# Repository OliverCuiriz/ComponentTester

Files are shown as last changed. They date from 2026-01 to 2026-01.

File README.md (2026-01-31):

# Component Tester – Proyecto de residencia profesional

Este repositorio contiene mi **proyecto de residencia profesional: Dispositivo para el diagnóstico y medición de componentes electrónicos**, desarrollado en el **Instituto Tecnológico de Tijuana** para el **CETis No. 58**.

El proyecto consiste de un probador de componentes electrónicos capaz de evaluar hasta **20 familias de componentes**, proporcionando información del estado de cada componente. El sistema está diseñado para apoyar el trabajo educativo y práctico en los estudiantes de electrónica en el CETis No. 58, permitiendo a los usuarios verificar el correcto funcionamiento de sus componentes electrónicos utilizados en sus prácticas de laboratorio.

## Familias de componentes soportados

- **Compuertas lógicas:** 74LS00 (NAND), 74LS02 (NOR), 74LS04 (NOT), 74LS08 (AND), 74LS32 (OR) y 74LS86 (XOR)
- **Reguladores de voltaje lineales:** LM317, LM337, LM7805, LM7812 y LM7912  
- **Diodos:** diodos rectificadores (familia 1N400x), LEDs y diodos Schottky 
- **Temporizador y OpAmp:** NE555 y LM741  
- **Motores:** servomotores SG90 / MOT1XX  y motor a pasos unipolar 28BYJ-48 
- **Otros componentes:** resistencias y capacitores

## Estructura del repositorio

Este repositorio está organizado en carpetas individuales que contienen todos los recursos relacionados con el proyecto. Estos incluyen el código fuente del proyecto, el esquema eléctrico, los archivos de diseño 3D de la PCB y la carcasa, y los recursos gráficos utilizados para el menú de la interfaz de usuario.

### Para abrir estos archivos se necesita el siguiente software:
- **Arduino IDE 2.6.3** recomendable
- **KiCad 9**
- **SolidWorks 2022**, o bien, cualquier software que pueda abrir archivos con extensión **.STL**
- **Photopea**, o bien, **Photoshop**

## Advertencias importantes
- Debido a un bug con los botones para navegar en el menú, se tiene que hacer un puente entre el pin 17 y pin 2 del ATmega2560. Esto se ve reflejado en el codigo fuente del proyecto pero no en el diseño de la PCB actual.
- El conector JST XH2.54 macho que se utiliza para el motor a pasos 28BYJ-48 está al revés en el diseño de la PCB.

**Ambos errores se pueden corregir modificando directamente la PCB en KiCad y generar otro diseño.** Si se quisiera fabricar la PCB tal y como está entonces se tienen que hacer esas dos modificaciones.

## Fotografía del proyecto

20251230_010616-Photoroom

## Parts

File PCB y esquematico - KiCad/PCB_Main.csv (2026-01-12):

Reference | Value | Datasheet | Footprint | Qty | DNP
C202,C206,C212,C300,C301,C302,C303,C304,C305,C306,C307,C308,C309,C401,C402,C600,C700 | 100nF | ~ | Capacitor_SMD:C_0805_2012Metric | 17
C500 | 10nF | ~ | Capacitor_SMD:C_0805_2012Metric | 1
R100,R101,R102,R105,R107,R110,R215,R228,R402 | 220 | ~ | Resistor_SMD:R_0805_2012Metric | 9
R103,R108,R111,R204,R205,R210,R211,R217,R218,R223,R224,R230,R231,R403,R503,R504 | 10k | ~ | Resistor_SMD:R_0805_2012Metric | 16
R104,R106,R109,R112,R500,R501 | 120k | ~ | Resistor_SMD:R_0805_2012Metric | 6
R203,R209,R216,R222,R229,R502 | 33k | ~ | Resistor_SMD:R_0805_2012Metric | 6
R300 | 330 | ~ | Resistor_SMD:R_0805_2012Metric | 1
R301 | 680 | ~ | Resistor_SMD:R_0805_2012Metric | 1
R400 | 2.2k | ~ | Resistor_SMD:R_0805_2012Metric | 1
R401 | 2.4k | ~ | Resistor_SMD:R_0805_2012Metric | 1
R900,R901,R902,R903,R904 | 4.7k | ~ | Resistor_SMD:R_0805_2012Metric | 5
R1000,R1001,R1002,R1100,R1101,R1102,R1103,R1104 | 1k | ~ | Resistor_SMD:R_0805_2012Metric | 8

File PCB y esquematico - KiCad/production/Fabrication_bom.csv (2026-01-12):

Designator | Footprint | Quantity | Value | LCSC Part #
_42, _41, _40, _39, _38, _37, _36, _35, _34, _33, _32, _31, _30, _29, _28, _27, _26, _25, _24, _23, _22, _21, _20, _19, _18, _17, _16, _15, _14, _13, _12, _11, _10, _9, _8, _7, _6, _5, _4, _3, _2, |  | 42
C202, C206, C209, C212, C300, C301, C302, C303, C304, C305, C306, C307, C308, C309, C401, C402, C600, C700 | 0805 | 18 | 100nF | C28233
C500 | 0805 | 1 | 10nF | C1710
R100, R101, R102, R105, R107, R110, R215, R228, R402 | 0805 | 9 | 220 | C17557
R1000, R1001, R1002, R1100, R1101, R1102, R1103, R1104 | 0805 | 8 | 1k | C17513
R103, R108, R111, R204, R205, R210, R211, R217, R218, R223, R224, R230, R231, R403, R503, R504 | 0805 | 16 | 10k | C17414
R104, R106, R109, R112, R500, R501 | 0805 | 6 | 150k | C17470
R203, R209, R216, R222, R229, R502 | 0805 | 6 | 33k | C17633
R300 | 0805 | 1 | 330 | C17630
R301 | 0805 | 1 | 680 | C17798
R400 | 0805 | 1 | 2.2k | C17520
R401 | 0805 | 1 | 2.4k | C17526
R900, R901, R902, R903, R904 | 0805 | 5 | 4.7k | C17673

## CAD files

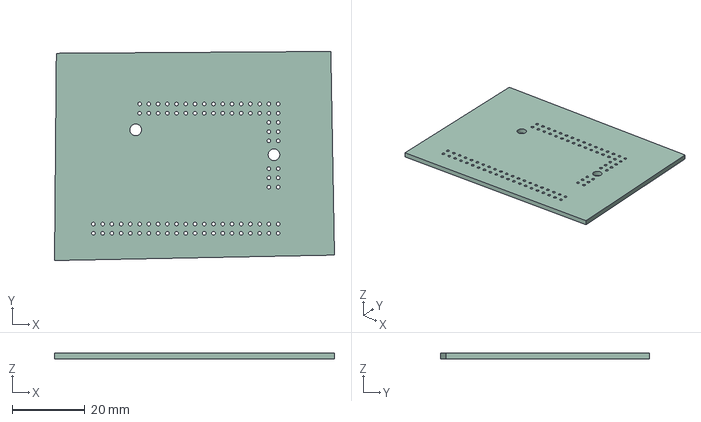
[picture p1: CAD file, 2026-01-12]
PCB y esquematico - KiCad/PCB_Main.step
77.0 x 57.5 x 1.60 mm

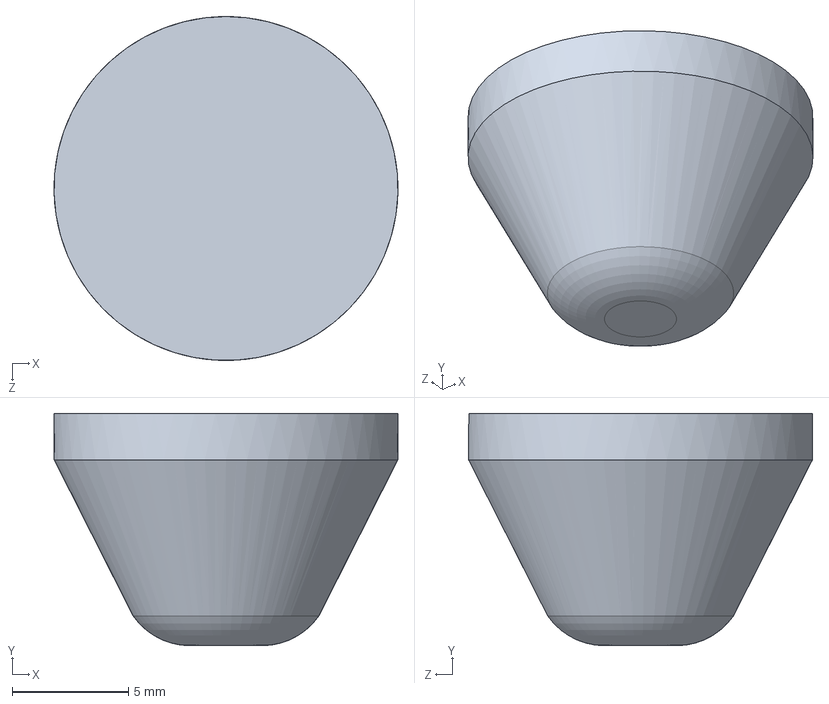
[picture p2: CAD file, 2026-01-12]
Diseños 3D - SolidWorks/PatasCaja.SLDPRT
14.8 x 10.0 x 14.8 mm

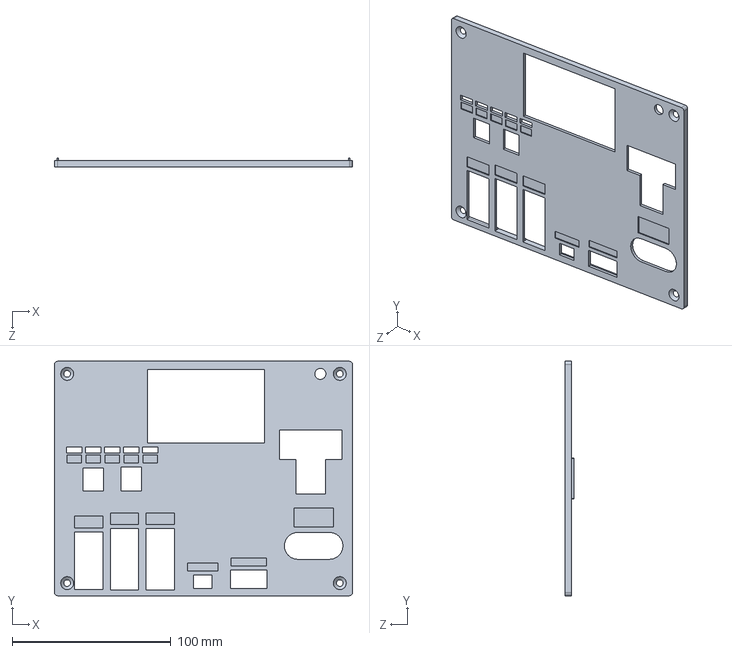
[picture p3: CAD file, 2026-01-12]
Diseños 3D - SolidWorks/Tapa.SLDPRT
188.0 x 148.0 x 5.50 mm

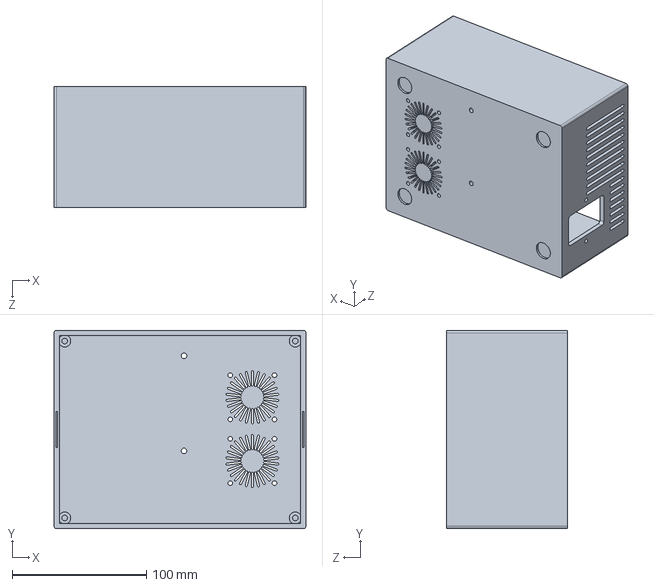
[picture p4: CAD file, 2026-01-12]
Diseños 3D - SolidWorks/Caja2.SLDPRT
188.0 x 148.0 x 90.0 mm

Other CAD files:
Diseños 3D - SolidWorks/Caja2.STL
Diseños 3D - SolidWorks/PatasCaja.STL
Diseños 3D - SolidWorks/Tapa.STL

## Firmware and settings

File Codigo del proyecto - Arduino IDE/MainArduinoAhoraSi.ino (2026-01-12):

#include <Arduino.h>
#include <stdio.h>
#include <U8g2lib.h>
#include "menu.h"
#include "iconos.h"
#include "Servo.h"

//SOLO PINES--------------------------------

//Reservados para la pantalla OLED 2.42 I2C

//#define D20 20 //SDA
//#define D21 21 //SCL

//SALIDAS DE VOLTAJE MOSFET
#define POSITIVE_15V_MOSFET_REG 23
#define NEGATIVE_15V_MOSFET_REG 24
#define POSITIVE_5V_REG 25
#define POSITIVE_5V_MEGA2560_MOSFET 26

//SWITCHES CHERRY MX
#define BOTON_UP_PIN 18     // INT4
#define BOTON_SELECT_PIN 2  // INT0
#define BOTON_DOWN_PIN 19   // INT5

//CONMUTADOR
#define RLV200 31
#define RLV201 32
#define RLV202 33
#define RLV203 34
#define RLV204 35

//PROBADOR 555
#define D41 41

//PROBADOR 741
#define D42 42
#define D43 43
//#define A6 A6

//PROBADOR SERVO MOTOR
#define D45 45

//PROBADOR DIODOS/LED
#define D47 47
#define D48 48
//#define A7 A7
//#define A8 A8

//PROBADOR RESISTENCIAS
#define D49 49
#define D50 50
#define D51 51
#define D52 52
#define D53 53
//#define A9 A9

//PROBADOR MOTOR A PASOS
#define D36 36
#define D37 37
#define D38 38
#define D39 39

//PROBADOR CAPACITORES
#define D28 28
#define D29 29
//#define A5 A5

//PROBADOR DE COMPUERTAS LOGICAS

#define Pin1Compuerta 4
#define Pin2Compuerta 5
#define Pin3Compuerta 6
#define Pin4Compuerta 7
#define Pin5Compuerta 8
#define Pin6Compuerta 9
#define Pin8Compuerta 10
#define Pin9Compuerta 11
#define Pin10Compuerta 12
#define Pin11Compuerta 13
#define Pin12Compuerta 14
#define Pin13Compuerta 15

//PINES PARA REGULADORES DE VOLTAJE LINEALES
#define pinLM7805 A0
#define pinLM7812 A1
#define pinLM317 A2
#define pinLM7912 A3
#define pinLM337 A4

//SOLO PINES---------------------------------

U8G2_SSD1306_128X64_NONAME_1_HW_I2C u8g2(U8G2_R0);

Servo motor;  // Objeto Servo global

const unsigned char* bitmap_icons[19] = {
    epd_bitmap__icono_555,
    epd_bitmap__icono_741,
    epd_bitmap__icono_74LS00,
    epd_bitmap__icono_74LS02,
    epd_bitmap__icono_74LS04,
    epd_bitmap__icono_74LS08,
    epd_bitmap__icono_74LS32,
    epd_bitmap__icono_74LS86,
    epd_bitmap__icono_LM317,
    epd_bitmap__icono_LM337,
    epd_bitmap__icono_LM7805,
    epd_bitmap__icono_LM7812,
    epd_bitmap__icono_LM7912,
    epd_bitmap__icono_capacitor,
    epd_bitmap__icono_diodo,
    epd_bitmap__icono_resistencia,
    epd_bitmap__icono_motor,  //servo
    epd_bitmap__icono_motor,  //stepper
    epd_bitmap__icono_signo_interrogacion,
};

const int NUM_ITEMS = 19;
const int CARACTERES_MAXIMOS = 20;

char menu_items[NUM_ITEMS][CARACTERES_MAXIMOS] = {
    {"NE555"},
    {"LM741"},
    {"74LS00 NAND"},
    {"74LS02 NOR"},
    {"74LS04 NOT"},
    {"74LS08 AND"},
    {"74LS32 OR"},
    {"74LS86 XOR"},
    {"LM317"},
    {"LM337"},
    {"LM7805"},
    {"LM7812"},
    {"LM7912"},
    {"Capacitor"},
    {"Diodo/LED"},
    {"Resistencia"},
    {"Servomotor"},
    {"Motor a pasos"},
    {"Acerca de"},
};

volatile bool flag_up = false;
volatile bool flag_down = false;
volatile bool flag_select = false;

int pantalla_actual = 0;

int item_seleccionado = 0;
int item_sel_previo;
int item_sel_siguiente;

void prueba_555();
void prueba_741();
void prueba_compuertas_logicas();
void prueba_LED();
void prueba_reguladores();
void prueba_capacitor();
void prueba_diodo();
void prueba_resistencia();
void prueba_servomotor();
void prueba_stepper();
void prueba_creditos();

void (*pruebas_electricas[19])() = {
    prueba_555,
    prueba_741,
    prueba_compuertas_logicas,
    prueba_compuertas_logicas,
    prueba_compuertas_logicas,
    prueba_compuertas_logicas,
    prueba_compuertas_logicas,
    prueba_compuertas_logicas,
    prueba_reguladores,
    prueba_reguladores,
    prueba_reguladores,
    prueba_reguladores,
    prueba_reguladores,
    prueba_capacitor,
    prueba_diodo,
    prueba_resistencia,
    prueba_servomotor,
    prueba_stepper,
    prueba_creditos
};

//---------------- ISR ----------------

void ISR_up() {
    flag_up = true;
}

void ISR_down() {
    flag_down = true;
}

void ISR_select() {
    flag_select = true;
}

void setup() {
    pinMode(BOTON_UP_PIN, INPUT);
    pinMode(BOTON_SELECT_PIN, INPUT);  // Pin 17 (pero conectado físicamente a 2)
    pinMode(BOTON_DOWN_PIN, INPUT);

    // Activar interrupciones en RISING (flanco de subida)
    attachInterrupt(digitalPinToInterrupt(BOTON_UP_PIN), ISR_up, RISING);
    attachInterrupt(digitalPinToInterrupt(BOTON_DOWN_PIN), ISR_down, RISING);
    attachInterrupt(digitalPinToInterrupt(BOTON_SELECT_PIN), ISR_select, RISING);

    pinMode(POSITIVE_15V_MOSFET_REG, OUTPUT);
    pinMode(NEGATIVE_15V_MOSFET_REG, OUTPUT);
    pinMode(POSITIVE_5V_REG, OUTPUT);
    pinMode(POSITIVE_5V_MEGA2560_MOSFET, OUTPUT);
    digitalWrite(POSITIVE_15V_MOSFET_REG, LOW);
    digitalWrite(NEGATIVE_15V_MOSFET_REG, LOW);
    digitalWrite(POSITIVE_5V_REG, LOW);
    digitalWrite(POSITIVE_5V_MEGA2560_MOSFET, LOW);

    pinMode(RLV200, OUTPUT);
    pinMode(RLV201, OUTPUT);
    pinMode(RLV202, OUTPUT);
    pinMode(RLV203, OUTPUT);
    pinMode(RLV204, OUTPUT);

    pinMode(Pin1Compuerta, OUTPUT);
    pinMode(Pin2Compuerta, OUTPUT);
    pinMode(Pin3Compuerta, INPUT_PULLUP);
    pinMode(Pin4Compuerta, OUTPUT);
    pinMode(Pin5Compuerta, OUTPUT);
    pinMode(Pin6Compuerta, INPUT_PULLUP);
    pinMode(Pin8Compuerta, INPUT_PULLUP);
    pinMode(Pin9Compuerta, OUTPUT);
    pinMode(Pin10Compuerta, OUTPUT);
    pinMode(Pin11Compuerta, INPUT_PULLUP);
    pinMode(Pin12Compuerta, OUTPUT);
    pinMode(Pin13Compuerta, OUTPUT);

    pinMode(D28, INPUT);
    pinMode(D29, OUTPUT);

    pinMode(D36, OUTPUT);
    pinMode(D37, OUTPUT);
    pinMode(D38, OUTPUT);
    pinMode(D39, OUTPUT);

    pinMode(D41, INPUT);

    pinMode(D42, OUTPUT);
    pinMode(D43, OUTPUT);

    pinMode(D45, OUTPUT);

    pinMode(D47, OUTPUT);
    pinMode(D48, OUTPUT);
    digitalWrite(D47, LOW);
    digitalWrite(D48, LOW);

    pinMode(D49, OUTPUT);
    pinMode(D50, OUTPUT);
    pinMode(D51, OUTPUT);
    pinMode(D52, OUTPUT);
    pinMode(D53, OUTPUT);

    motor.attach(D45); //servo

    inicializarOLED();
}

void loop() {
    // ---- PROCESAR BOTÓN UP ----
    if (flag_up && digitalRead(BOTON_UP_PIN) == LOW) {
        flag_up = false;
        if (pantalla_actual == 0) {
            item_seleccionado--;
            if (item_seleccionado < 0) item_seleccionado = NUM_ITEMS - 1;
        }
    }

    // ---- PROCESAR BOTÓN DOWN ----
    if (flag_down && digitalRead(BOTON_DOWN_PIN) == LOW) {
        flag_down = false;
        if (pantalla_actual == 0) {
            item_seleccionado++;
            if (item_seleccionado >= NUM_ITEMS) item_seleccionado = 0;
        }
    }

    // ---- PROCESAR BOTÓN SELECT ----
    if (flag_select && digitalRead(BOTON_SELECT_PIN) == LOW) {
        flag_select = false;
        pantalla_actual ^= 1;   // cambia entre menú y prueba
    }

    if (pantalla_actual == 0) {
    motor.detach();
    desactivar_MOSFETS();
    desactivar_conmutador();
    }

    // ---- ÍNDICES DEL MENÚ ----
    item_sel_previo = item_seleccionado - 1;
    if (item_sel_previo < 0) item_sel_previo = NUM_ITEMS - 1;

    item_sel_siguiente = item_seleccionado + 1;
    if (item_sel_siguiente >= NUM_ITEMS) item_sel_siguiente = 0;

    u8g2.firstPage();
    do {
        if (pantalla_actual == 0) {
            u8g2.drawXBMP(0,0,5,5,epd_bitmap__contorno_esq_sup_izq);
            u8g2.drawXBMP(123,0,5,5,epd_bitmap__contorno_esq_sup_der);
            u8g2.drawXBMP(0,59,5,5,epd_bitmap__contorno_esq_inf_izq);
            u8g2.drawXBMP(123,59,5,5,epd_bitmap__contorno_esq_inf_der);
            u8g2.drawXBMP(5,0,118,1,epd_bitmap__contorno_linea_sup);
            u8g2.drawXBMP(5,63,118,1,epd_bitmap__contorno_linea_inf);
            u8g2.drawXBMP(0,5,1,54,epd_bitmap__contorno_linea_izq);
            u8g2.drawXBMP(127,5,1,54,epd_bitmap__contorno_linea_der);
            
            u8g2.drawXBMP(122,5,3,53,epd_bitmap__scroll_background);
            u8g2.drawXBMP(2,22,119,21,epd_bitmap__seleccion_de_item_background);
            u8g2.drawBox(122, (53/(NUM_ITEMS-2))*item_seleccionado + 4, 3, 53/NUM_ITEMS);

            u8g2.setFont(u8g2_font_7x14_tf); 
            u8g2.drawStr(25, 16, menu_items[item_sel_previo]);
            u8g2.drawStr(25, 37, menu_items[item_seleccionado]);
            u8g2.drawStr(25, 58, menu_items[item_sel_siguiente]);

            u8g2.drawXBMP(5,3,16,16,bitmap_icons[item_sel_previo]); 
            u8g2.drawXBMP(5,24,16,16,bitmap_icons[item_seleccionado]);   
            u8g2.drawXBMP(5,45,16,16,bitmap_icons[item_sel_siguiente]);   
        } else {
            pruebas_electricas[item_seleccionado]();
        }
    } while (u8g2.nextPage());
}



void prueba_reguladores() {
    static float inputVoltage = 0.0;
    static float inputCurrent = 0.0;
    float R_reg = 0.00001;
    static unsigned long ultimo_muestreo = 0;
    const unsigned long intervalo_muestreo = 500;
    const float Vmin = -15.0;
    const float Vmax = 15.0;
    int analogPin = -1;
    const char* nombre_componente = "";
    const char* mensaje_medicion = "";
    bool es_variable = false;

    switch (item_seleccionado) {
        case 8:
            analogPin = pinLM317;
            nombre_componente = "LM317";
            mensaje_medicion = "OBJETIVO: 1.2V a 13V";
            es_variable = true;
            R_reg = 200.0;
            digitalWrite(POSITIVE_15V_MOSFET_REG, HIGH);
            break;
        case 9:
            analogPin = pinLM337;
            nombre_componente = "LM337";
            mensaje_medicion = "OBJETIVO: -1.2V a -13V";
            es_variable = true;
            R_reg = 200.0;
            digitalWrite(NEGATIVE_15V_MOSFET_REG, HIGH);
            break;
        case 10:
            analogPin = pinLM7805;
            nombre_componente = "LM7805";
            mensaje_medicion = "OBJETIVO: 5V";
            es_variable = false;
            R_reg = 97.0;
            digitalWrite(POSITIVE_15V_MOSFET_REG, HIGH);
            break;
        case 11:
            analogPin = pinLM7812;
            nombre_componente = "LM7812";
            mensaje_medicion = "OBJETIVO: 12V";
            es_variable = false;
            R_reg = 200.0;
            digitalWrite(POSITIVE_15V_MOSFET_REG, HIGH);
            break;
        case 12:
            analogPin = pinLM7912;
            nombre_componente = "LM7912";
            mensaje_medicion = "OBJETIVO: -12V";
            es_variable = false;
            R_reg = 200.0;
            digitalWrite(NEGATIVE_15V_MOSFET_REG, HIGH);
            break;
        default:
            return;
    }

    unsigned long tiempo_actual = millis();
    if (tiempo_actual - ultimo_muestreo >= intervalo_muestreo) {
        int sensorValue = analogRead(analogPin);
        float voltageADC = sensorValue * (5.0 / 1023.0);
        inputVoltage = mapFloat(voltageADC, 0.17, 4.17, Vmin, Vmax);
        inputCurrent = inputVoltage / R_reg;
        ultimo_muestreo = tiempo_actual;
    }

    u8g2.setFont(u8g2_font_7x13_tf);
    u8g2.drawStr(44, 13, nombre_componente);

    u8g2.setFont(u8g2_font_5x7_tf);
    if (es_variable) {
        u8g2.drawStr(85, 30, "MUEVA EL");
        u8g2.drawStr(96, 40, "POT");
    }

    u8g2.setFont(u8g2_font_7x13_tf);
    u8g2.drawStr(0, 32, "V:");
    u8g2.setCursor(15, 32);
    u8g2.print(inputVoltage, 3);
    u8g2.drawStr(65, 32, "V");

    u8g2.drawStr(0, 47, "I:");
    u8g2.setCursor(15, 47);
    u8g2.print(inputCurrent, 3);
    u8g2.drawStr(60, 47, "A");

    u8g2.setFont(u8g2_font_5x7_tf);
    u8g2.drawStr(0, 64, mensaje_medicion);
}

void defaultt() {
  pinMode(Pin1Compuerta, OUTPUT);
  pinMode(Pin2Compuerta, OUTPUT);
  pinMode(Pin3Compuerta, INPUT_PULLUP);
  pinMode(Pin4Compuerta, OUTPUT);
  pinMode(Pin5Compuerta, OUTPUT);
  pinMode(Pin6Compuerta, INPUT_PULLUP);
  pinMode(Pin8Compuerta, INPUT_PULLUP);
  pinMode(Pin9Compuerta, OUTPUT);
  pinMode(Pin10Compuerta, OUTPUT);
  pinMode(Pin11Compuerta, INPUT_PULLUP);
  pinMode(Pin12Compuerta, OUTPUT);
  pinMode(Pin13Compuerta, OUTPUT);
}

void CasoEspecialNOT() { // Configura pines para el 74LS04 (6 compuertas NOT)
  pinMode(Pin1Compuerta, OUTPUT);
  pinMode(Pin2Compuerta, INPUT_PULLUP);
  pinMode(Pin3Compuerta, OUTPUT);
  pinMode(Pin4Compuerta, INPUT_PULLUP);
  pinMode(Pin5Compuerta, OUTPUT);
  pinMode(Pin6Compuerta, INPUT_PULLUP);
  pinMode(Pin8Compuerta, INPUT_PULLUP);
  pinMode(Pin9Compuerta, OUTPUT);
  pinMode(Pin10Compuerta, INPUT_PULLUP);
  pinMode(Pin11Compuerta, OUTPUT);
  pinMode(Pin12Compuerta, INPUT_PULLUP);
  pinMode(Pin13Compuerta, OUTPUT);
}

void CasoEspecialNOR() { // Configura pines para el 74LS02 (Compuerta NOR estan voltadas las entradas y salidas)
  pinMode(Pin1Compuerta, INPUT_PULLUP);
  pinMode(Pin2Compuerta, OUTPUT);
  pinMode(Pin3Compuerta, OUTPUT);
  pinMode(Pin4Compuerta, INPUT_PULLUP);
  pinMode(Pin5Compuerta, OUTPUT);
  pinMode(Pin6Compuerta, OUTPUT);
  pinMode(Pin8Compuerta, OUTPUT);
  pinMode(Pin9Compuerta, OUTPUT);
  pinMode(Pin10Compuerta, INPUT_PULLUP);
  pinMode(Pin11Compuerta, OUTPUT);
  pinMode(Pin12Compuerta, OUTPUT);
  pinMode(Pin13Compuerta, INPUT_PULLUP);
}

// Función principal para compuertas lógicas
void prueba_compuertas_logicas() {
    const char* nombre_componente = "";

    u8g2.setFont(u8g2_font_5x7_tf);
    u8g2.drawStr(10, 60, "Espere 4-5s por prueba");

    switch (item_seleccionado) {
        case 2: 
        nombre_componente = "74LS00 NAND"; 
        digitalWrite(POSITIVE_5V_MEGA2560_MOSFET, HIGH); 
        break;
        case 3: 
        nombre_componente = "74LS02 NOR"; 
        digitalWrite(POSITIVE_5V_MEGA2560_MOSFET, HIGH); 
        CasoEspecialNOR(); 
        break;
        case 4: nombre_componente = "74LS04 NOT"; 
        digitalWrite(POSITIVE_5V_MEGA2560_MOSFET, HIGH); 
        CasoEspecialNOT(); 
        break;
        case 5: 
        nombre_componente = "74LS08 AND"; 
        digitalWrite(POSITIVE_5V_MEGA2560_MOSFET, HIGH); 
        break;
        case 6: 
        nombre_componente = "74LS32 OR"; 
        digitalWrite(POSITIVE_5V_MEGA2560_MOSFET, HIGH); 
        break;
        case 7: 
        nombre_componente = "74LS86 XOR"; 
        digitalWrite(POSITIVE_5V_MEGA2560_MOSFET, HIGH); 
        break;
        default: 
        return;
    }

    u8g2.setFont(u8g2_font_7x13_tf);
    u8g2.drawStr(30, 13, nombre_componente);



    if (item_seleccionado == 2) {
        u8g2.setFont(u8g2_font_5x7_tf);
        u8g2.drawStr(0, 25, "Gate 1:");
        u8g2.drawStr(64, 25, "Gate 4:");
        u8g2.drawStr(0, 35, "Gate 2:");
        u8g2.drawStr(64, 35, "Gate 3:");
        pruebaNAND();
    } else if (item_seleccionado == 3) {
        u8g2.setFont(u8g2_font_5x7_tf);
        u8g2.drawStr(0, 25, "Gate 1:");
        u8g2.drawStr(64, 25, "Gate 4:");
        u8g2.drawStr(0, 35, "Gate 2:");
        u8g2.drawStr(64, 35, "Gate 3:");
        pruebaNOR();
    } else if (item_seleccionado == 4) {
        u8g2.setFont(u8g2_font_5x7_tf);
        u8g2.drawStr(0, 25, "Gate 1:");
        u8g2.drawStr(64, 25, "Gate 6:");
        u8g2.drawStr(0, 35, "Gate 2:");
        u8g2.drawStr(64, 35, "Gate 5:");
        u8g2.drawStr(0, 45, "Gate 3:");
        u8g2.drawStr(64, 45, "Gate 4:");
        pruebaNOT();
    } else if (item_seleccionado == 5) {
        u8g2.setFont(u8g2_font_5x7_tf);
        u8g2.drawStr(0, 25, "Gate 1:");
        u8g2.drawStr(64, 25, "Gate 4:");
        u8g2.drawStr(0, 35, "Gate 2:");
        u8g2.drawStr(64, 35, "Gate 3:");
        pruebaAND();
    } else if (item_seleccionado == 6) {
        u8g2.setFont(u8g2_font_5x7_tf);
        u8g2.drawStr(0, 25, "Gate 1:");
        u8g2.drawStr(64, 25, "Gate 4:");
        u8g2.drawStr(0, 35, "Gate 2:");
        u8g2.drawStr(64, 35, "Gate 3:");
        pruebaOR();
    } else if (item_seleccionado == 7) {
        u8g2.setFont(u8g2_font_5x7_tf);
        u8g2.drawStr(0, 25, "Gate 1:");
        u8g2.drawStr(64, 25, "Gate 4:");
        u8g2.drawStr(0, 35, "Gate 2:");
        u8g2.drawStr(64, 35, "Gate 3:");
        pruebaXOR();
    }
}

void pruebaNAND() {
    static bool gateOK[4] = {false, false, false, false};
    static unsigned long ultimo_muestreo = 0;

    static int iter = 0;
    static int combo = 0;
    static int rep1 = 0, rep2 = 0, rep3 = 0, rep4 = 0;
    static bool consistente1 = true, consistente2 = true, consistente3 = true, consistente4 = true;
    static int PruebaSalida1 = 0, PruebaSalida2 = 0, PruebaSalida3 = 0, PruebaSalida4 = 0;

    // Para mostrar "TEST" y pausa de 1.5s
    static bool mostrando_resultado = false;
    static unsigned long tiempo_resultado = 0;
    const unsigned long duracion_resultado = 1500;  // 1.5 segundos

    unsigned long tiempo_actual = millis();

    if (mostrando_resultado) {
        // Durante 1.5s mostrar resultado final
        if (tiempo_actual - tiempo_resultado >= duracion_resultado) {
            mostrando_resultado = false;
            iter = 0;
            consistente1 = consistente2 = consistente3 = consistente4 = true;
        }
    } else {
        // Prueba normal
        if (tiempo_actual - ultimo_muestreo >= 1) {
            if (combo == 0) {
                digitalWrite(Pin1Compuerta, LOW); digitalWrite(Pin2Compuerta, LOW);
                digitalWrite(Pin4Compuerta, LOW); digitalWrite(Pin5Compuerta, LOW);
                digitalWrite(Pin9Compuerta, LOW); digitalWrite(Pin10Compuerta, LOW);
                digitalWrite(Pin12Compuerta, LOW); digitalWrite(Pin13Compuerta, LOW);
            } else if (combo == 1) {
                digitalWrite(Pin1Compuerta, HIGH); digitalWrite(Pin2Compuerta, LOW);
                digitalWrite(Pin4Compuerta, HIGH); digitalWrite(Pin5Compuerta, LOW);
                digitalWrite(Pin9Compuerta, LOW); digitalWrite(Pin10Compuerta, HIGH);
                digitalWrite(Pin12Compuerta, LOW); digitalWrite(Pin13Compuerta, HIGH);
            } else if (combo == 2) {
                digitalWrite(Pin1Compuerta, LOW); digitalWrite(Pin2Compuerta, HIGH);
                digitalWrite(Pin4Compuerta, LOW); digitalWrite(Pin5Compuerta, HIGH);
                digitalWrite(Pin9Compuerta, HIGH); digitalWrite(Pin10Compuerta, LOW);
                digitalWrite(Pin12Compuerta, HIGH); digitalWrite(Pin13Compuerta, LOW);
            } else if (combo == 3) {
                digitalWrite(Pin1Compuerta, HIGH); digitalWrite(Pin2Compuerta, HIGH);
                digitalWrite(Pin4Compuerta, HIGH); digitalWrite(Pin5Compuerta, HIGH);
                digitalWrite(Pin9Compuerta, HIGH); digitalWrite(Pin10Compuerta, HIGH);
                digitalWrite(Pin12Compuerta, HIGH); digitalWrite(Pin13Compuerta, HIGH);
            }

            if (combo >= 0 && combo <= 3) {
                if (digitalRead(Pin3Compuerta) == (combo == 3 ? LOW : HIGH)) PruebaSalida1++;
                if (digitalRead(Pin6Compuerta) == (combo == 3 ? LOW : HIGH)) PruebaSalida2++;
                if (digitalRead(Pin8Compuerta) == (combo == 3 ? LOW : HIGH)) PruebaSalida3++;
                if (digitalRead(Pin11Compuerta) == (combo == 3 ? LOW : HIGH)) PruebaSalida4++;
            }

            combo++;

            if (combo > 3) {
                if (iter == 0) {
                    rep1 = PruebaSalida1; rep2 = PruebaSalida2; rep3 = PruebaSalida3; rep4 = PruebaSalida4;
                } else {
                    if (PruebaSalida1 != rep1) consistente1 = false;
                    if (PruebaSalida2 != rep2) consistente2 = false;
                    if (PruebaSalida3 != rep3) consistente3 = false;
                    if (PruebaSalida4 != rep4) consistente4 = false;
                }

                iter++;
                combo = 0;
                PruebaSalida1 = 0; PruebaSalida2 = 0; PruebaSalida3 = 0; PruebaSalida4 = 0;

                if (iter >= 40) {
                    gateOK[0] = consistente1 && rep1 == 4;
                    gateOK[1] = consistente2 && rep2 == 4;
                    gateOK[2] = consistente3 && rep3 == 4;
                    gateOK[3] = consistente4 && rep4 == 4;

                    mostrando_resultado = true;
                    tiempo_resultado = tiempo_actual;
                }
            }

            ultimo_muestreo = tiempo_actual;
        }
    }

    u8g2.setFont(u8g2_font_5x7_tf);
    u8g2.setCursor(35, 25);
    if (mostrando_resultado) {
        u8g2.print(gateOK[0] ? "OK" : "FALLA");
    } else {
        u8g2.print("TEST");
    }

    u8g2.setCursor(100, 35);
    if (mostrando_resultado) {
        u8g2.print(gateOK[1] ? "OK" : "FALLA");
    } else {
        u8g2.print("TEST");
    }

    u8g2.setCursor(35, 35);
    if (mostrando_resultado) {
        u8g2.print(gateOK[2] ? "OK" : "FALLA");
    } else {
        u8g2.print("TEST");
    }

    u8g2.setCursor(100, 25);
    if (mostrando_resultado) {
        u8g2.print(gateOK[3] ? "OK" : "FALLA");
    } else {
        u8g2.print("TEST");
    }

    defaultt();
}
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
